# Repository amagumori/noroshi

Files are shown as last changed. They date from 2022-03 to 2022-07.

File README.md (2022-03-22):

# Noroshi
#### Portable LTE/Wifi Radio Terminal

Noroshi is a project that aims to explore the question:
**What capabilities enabled by the Internet are compelling, and...**
**How can we provide those capabilities in a way that is:**

+ More decentralized
+ More autonomous
+ More empowering for the individual?

The Internet of today is a vastly different place from the days of its infancy.  We've moved from a "many-servers" paradigm to a "many-clients" paradigm, as monolithic platforms have conquered the space.  The majority of Internet communication now exists in a TV-like paradigm, with a single-digit number of service providers.

These providers provide a variety of technological capabilities, each with unique social and cultural relevance, which overlap and can be broadly grouped into "live" and "static" groups, though the "liveness" is a spectrum.

### Live Capabilities
**Streaming** - Youtube, Twitch, IG Live, FB Live.
**Group Chat** - Discord, Slack, IRC (barely hanging on)
**Messaging** - Every platform

### Slow Capabilities
**Microblogging** - Twitter, IG, FB
**File Sharing** - Google Drive, Dropbox, OneDrive, etc
**Email** - Gmail, of course
**~~Blogging~~**  doesn't exist anymore
**~~Websites~~** don't exist anymore (in social or cultural relevance)

---

What would it look like to envision off-internet networking at a community or friend-group level?  And what capabilities could we provide while remaining free from the Internet or monolithic service providers?

The Internet provides a variety of capabilities, from realtime, streaming applications to static data.  We aim to attack this problem on both ends - one, the streaming, realtime, low-latency side of Internet functionality, using the NRF9160 to communicate over LTE; and the other, the slower, static side, using the ESP32 to enable peer-to-peer data exchange over Wifi.

### On the LTE side, a "radio" mode of using internet connectivity.  

+ Secure, frictionless, realtime push-to-talk communication, as with a VHF/UHF radio.

+ Broadcasting and receiving streaming audio, as with an FM radio.

Both of these applications are out of reach for the "regular citizen", especially within a city.  Ham radio does not enable encrypted communications, and is limited by regulation to a pure hobbyist pursuit.  Ham cannot be used for group-exclusive communications, and has a variety of limitations and frictions that prevent it from being a viable day-to-day communication tool.

On the other side, to set up a private VHF/UHF PTT capability within a city, a customer must lease radios from a vertically integrated provider, because only these will own repeater space on the local coverage points; you can get licensed, but a prohibitively expensive outlay is required to actually achieve full coverage in a metropolitan area.

These regulatory limitations prevent VHF/UHF from being used in an autonomous, secure, and self-sufficient manner.  Either you're a HAM, limited to communications-as-a-hobby - QSLs, etc; or you're a lessee of service from a provider.

This project aims to take a specific, compelling application of cell technology (low-latency audio streaming) and build a dedicated, stripped-down, and focused product for it, providing a more autonomous and open-source way to use IoT without relying on current monolithic tech ecosystems.

The goal of this project is to provide a different vision of communication over cell networks.  The value of this radio is in it being a dedicated object with a focused purpose and frictionless UX.  We aim for the main mode of interaction with the object to be physical, with the screen providing extremely concise information.  As far as possible from the interaction mode of a mobile app, we want this to be a physical device that fits well in the hand, has interactions recognizable by feel, and can be used without looking at the screen.

To illustrate this, mobile apps like Zello enable PTT functionality; but they also require buying into the entire cell phone ecosystem, from the hardware to the OS, and your communications go through an opaque signed binary to Zello's servers.  Cell phone apps have ever-present interaction friction at every level - multiple touch interactions to talk by default (unlocking the screen to hit the talk button, etc); coexisting with other apps on the phone, which can interfere with its operation or availability; difficulty of manipulating the phone in the hand; and so on.

Similarly, internet radio already exists; but there is no *dedicated* and simplified way to interact with it, and as such the technology is effectively dead.  Streaming video platforms such as Youtube or Twitch are now the dominant platform for audio streaming, because they provide lower barriers to entry and vastly better UX than Shoutcast or similar.  By providing a simple and frictionless way to broadcast and receive audio in realtime, we aim to empower individual users and rejuvenate a dying medium, with everyone being the owner, operator, and DJ of their own radio station, not through an app, but through a dedicated physical device.  Ultimately, I envision this as pushing a second age of radio, with individuals able to frictionlessly "speak" to an audience - every individual having space within the frequency spectrum, free of barriers to entry.

### Wifi / LoRa - Wifi for a peer-to-peer sneakernet, decoupled from the Internet.

The aim of the Wifi side of functionality is to provide a way to slowly and organically share static data among a local community without using the Internet - in other words, to provide a truly autonomous form of social networking.  

This aims at a similar area as existing platforms such as Mastodon that aim to provide decentralized alternatives to monolithic social networks. This project aims to provide a generic and open-ended framework for all types of information exchange - social applications like microblogging, as well as media and file sharing, forums, and wikis.  It also aims to provide a hardy and simple method for updating this shared state, that can be used not just with WiFi, but with other wireless connections - LoRa, etc.

## Design Methodology

We envision a community's "shared state" as a traditional filesystem, with each member possessing a directory.  At a global level, there are N numbers of dedicated *reserved filenames* that indicate the contextual meaning of the data.  a directory named "blog" will be viewed on the client side as that user's blog, similar to a twitter feed.  all files within that directory will be parsed as Markdown and displayed as blog entries in a time-sorted list based on the file's creation date.

### Connection

The public keys of "friends" in the community are indicated by the SSID broadcasted by the peer AP, and the shared secret is used as the WPA2 password.  With both devices in Station+SoftAP mode, operating in both modes simultaneously, we open a TCP socket connection.

### Syncing

After connecting to the peer, both clients send hashes of each "friend"'s directory, as well as timestamps of its last update.  both clients symmetrically use this info to determine the friends for which they own newer data, and the friends for which they own older data.

Another *reserved file* is the "friends" file.  This file exists within each person's directory at the top level, and describes permission groups (The ESP32 has a stripped-down libc, but runs on FreeRTOS, and has a very spare filesystem abstraction layer.)

We use **librsync**, specifically **rdiff**, to handle generating file signatures, deltas, and patching.  Signature files are generated AoT, not at connection time.

The friend directory trees are walked with **ftw**, permissions are checked, and the fds of new / updated signature files are pushed to a queue.  These signature files are compressed and sent; used to generate deltas; and deltas are compressed and sent, completing the sync process.

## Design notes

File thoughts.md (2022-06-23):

# ansible

---

chain of events on boot:

app_event_start

  concurrently:
    modem - on_all_states - setup()
    modem - EVENT_LTE_CONNECTED

    **ui** - load "codeplug"
    render start screen  

  EVENT_LTE_CONNECTED:
    **ui** show codeplug server list (contact list?)
    
    do ui stuff, handle inputs in ui until:

  EVENT_UI_CONNECT_TO_TALKSERVER:
    
    pass codeplug data to motorola in ui_msg 
    attempt mqtt connect
      success: MOTOROLA_EVENT_TALK_CONNECTED
      fail:    MOTOROLA_EVENT_TALK_CONNECT_FAIL
      
      motorola module handles everything from here, with events for when ppl talk etc.

  EVENT_UI_CONNECT_TO_STATION:
    
    pass codeplug data to radio in ui_msg
    attempt socket connect
      success: RADIO_EVENT_CONNECTED
      fail: RADIO_EVENT_CONNECT_FAIL
    
    etc.

  and that's pretty much it for now.
  other states of note:

    RADIO_EVENT_START_BROADCAST

---

[Scalable Protocols for Authenticated Group Key Exchange](https://www.cs.umd.edu/~jkatz/papers/multi-auth.pdf)

[Wideband Antenna - 8dBi](https://www.amazon.com/Wide-Band-Internal-LoRa-Antenna/dp/B08WJQ7ZS3)
700-2700Mhz but gotta see performance on the datasheet

[Battery Management IC shootout](https://hackaday.io/project/169422-iot-ups/log/177680-battery-management)

[1.3" 128x64 OLED module - $6.50](https://www.adafruit.com/product/5228)

### a low-power, secure push-to-talk device 

#### in the future, a portable silent sneakernet terminal, and a medium of secure data sync over other radio methods 

## TO DO

+ GPIO interface for buttons and leds.  reference sdk lib/dk_buttons

+ in-depth look at what's needed in the UI, how many inputs, how many views, and what they look like.  get concrete lists and trees for this.

+ suss out an explicit plan for doing voice over MQTT and what that protocol looks like.

+ begin testing radio module, delete all the cruft.

+ I2S interface to mic, speaker, and line out.  put this into the HW design in Kicad as well.

+ crypto - begin to look at what a secure talkgroup looks like and how to handle session establishment and TX / RX.

--

### wifi side - ESP8266

take a look at ESP datasheet.

my community versioned filesystem idea but certain items are ONLY synced in person, not over the internet.  

**1/27/22**

[I2S documentation for spekker](https://infocenter.nordicsemi.com/index.jsp?topic=%2Fstruct_nrf91%2Fstruct%2Fnrf9160.html&cp=2_0)

probably handle mic and speaker with both sides of the I2S interface for better quality than PDM

the I2S driver already implements dubble bubfering behind the scenes, so that's one less thing to do, this way we can shove audio frames coming off the MQTT interface directly towards the I2S RX / TX buffers and then just play what we get, configuring the RXTXDCNT.MAXWORDS as needed.

**1/22/22**

completely dropping the whole LWm2m thing

MQTT with QOS-1 (ack'd) frames.
assemble in order on the recipient end.
send a header with frame count.

### RTOS modules (zephyr)

UI module - UI events, interactions through LVGL

HW module - the physical buttons - this is tightly coupled to UI and could even combine ...?

MODEM module - self explanatory

do you separate out MQTT protocol layer into its own module? leaning towards ...no...

*radio protocol over LTE*

i wanted to just do LWm2m and i'll fall back if my idea ends up not working, but...

we essentially just want in-order packet delivery.

so, you make a recording using the PDM microphone, let's say 30 seconds max transmit time.

this gets split into frames, with a header:

**header**

+ u32 id of transmitter

+ u16 frame count

+ u32[] recipient ids, and if this[0] is 0 then it's a public message.  server handles that

**frame**

+ u16 sequence number

+ u16 buffer of FRAMESIZE 

but actually i don't like this.  i think..

header: transmitter id, recipients

frame: sequence number, buffer, bool done?

this way we can opportunistically shove encoded frames out the door
instead of filling a on-device buffer first.

*LTE-M / NB-IoT*

NRF9160

enables PTT, in concert with a MQTT server.

kicking around the idea of having "freqs" on the server.

enable both internet-radio (RX only) and communication (TX / RX) applications.

*Wi-Fi*

ESP8266 etc.

enables "distributed sneakernet".

essentially to have a...something, git repo + wiki + forum + fileserver, some kind of distributed locus of info (files), "slow" communications (long-form discussions, "letters") , and ... other stuff

the ESP8266 passively updates this network, when in range of a known and trusted *beacon*.

`security weak point!` 
*beacon* key exchange can be done over LTE / Internet or via NFC, in person.

the group data store can be viewed as some kind of tree that can be diff'd, similar to git or react?

*LoRaWAN* 

only having Wifi capability severely limits the capabilities of *beacons*.

LoRa enables better capability for long-range, passive syncing of the datastore state.

the more "mirrors" / *beacons* the better, so it follows that having more of them be able to connect is important.

--- 

there's a fundamental question of whether to enable backchanneling over the internet at all.

at the very least, file/comm permissions should allow a "No-Internet" status.
these updates would still be synced to the state (not their actual content, but a dummy update).

the "No-Internet" status would mark them for updating if ansible receives a diff from the local network with the relevant data.

if updated via internet, would only display a "Encrypted: Local Only" message as displayed in the rendering of the wiki/filestore/whatever.

---

the radio stores contact sets, from entire-community-level to smaller subgroups.

files are worked on a sans-internet computer, then updates are encrypted and synced to radio.

radio then transfers updates to each user, who holds a copy of the total state.
this happens over LTE

## Hardware Design

**AS SIMPLE AS POSSIBLE**
that means as few inputs as possible.

all physical buttons, no touch.  medium-rugged and repairable design.

shooting for ~1.75" width x 4-5"?  depth whatever.  it can be a lil thicc

3Ah+ battery.  aiming for slightly chunky nextel form factor...but appealing.

pcbway - UTR-8100 resin, dyed after the fact?

OLED module fr sure.  1-1,5"

*input interface*

+ PTT button, located as on a motorola XPR

PTT button is essentially a no go because it's for PTT and only PTT, always.

+ up/down buttons on PTT side.

+ thumb button on opposite side.

this way you grip across face of radio, index finger PTT, thumbs up/down 

+ some kind of wheel.  probably volume / power knob located top.

this is also off limits design wise.  volume / pwr only.

it's gonna need 1 or 2 more inputs than this but hopefully not many more.

*connectors*

SMA(m) connector.

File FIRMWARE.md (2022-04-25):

# hardware

## audio stage

MAX9880 audio codec - I2S - both voiceband and high-quality stereo input / dac / amp covered
audio out also covered 

# firmware structure

microphone interface: 

https://infocenter.nordicsemi.com/index.jsp?topic=%2Fcom.nordic.infocenter.nrf52832.ps.v1.1%2Fpdm.html

## transmit

MQTT session is set up on NRF9160 over TLS.

Microphone -> TLV320ADC or similar -> NRF9160 I2S input.

TLV320 can filter up the signal real nice to give to Codec2.

NRF9160's FPU: Codec2/FreeDV encode payload from voice data.
 
this payload could be a stack of smaller payloads, or just one big payload.

at this point, encrypt with CryptoCell or whatever?  but don't, at first..

voice payload is TX'd to MQTT broker.

## receive

decrypt

Codec2 / FreeDV decode

i2s/c out -> amp -> speaker

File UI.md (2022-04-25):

# UI Plan

#### boot screen

# select server

PTT and "radio" happen over a "repeater" server.
you have a list of these in the "codeplug". 

codeplug will automatically GET each server with your shared secret, if you have it.

  if auth:
    server will return list of your auth'd talkgroups and active stations

  if no auth:
    servers will return list of public stations

if auth fails / no key, list item for server will show NO-AUTH
if auth success, list item for server will look good

we want a way to dynamically access anyone's "radio station" at any time
without a server-switch interaction

we want to send a MQTT notify if a talkgroup member starts broadcasting

and then if we want to connect to that "radio station"...
  we open a different (or OTHER) socket conn to that server.

broadcasting happens thru your "home" repeater by default

## PTT

### select talkgroup

#### connecting to server... view

opens MQTT connection to server, start listening

#### PTT view: talkgroups and members

default view shows active talkgroups

alternate view lists all server members

#### Talkgroup view

talkgroup name, then "talking" view, if someone's talking

alternate view lists all talkgroup members

#### talking (transmitting) view

"transmitting" icon + name of talkgroup + waveform view

#### listening ( receiving ) view

talker's user icon + talkers name + waveform view

---

#### connecting to radio... view

have a "tuning" sound effect like JSRF

## Radio

### tuning view

show list of all active stations on all servers 

  public stations on un'authd servers
  
  public + private stations on auth'd servers

Broadcaster's user icon OR custom station icon

station name

broadcaster name: repeater name

lil waveform animation view??

### Radio Station ID Jingle

an audio clip "header" that plays when you connect.

broadcaster sends this to repeater when beginning broadcast

repeater saves it for the life of the broadcast session, sends it to each new listener

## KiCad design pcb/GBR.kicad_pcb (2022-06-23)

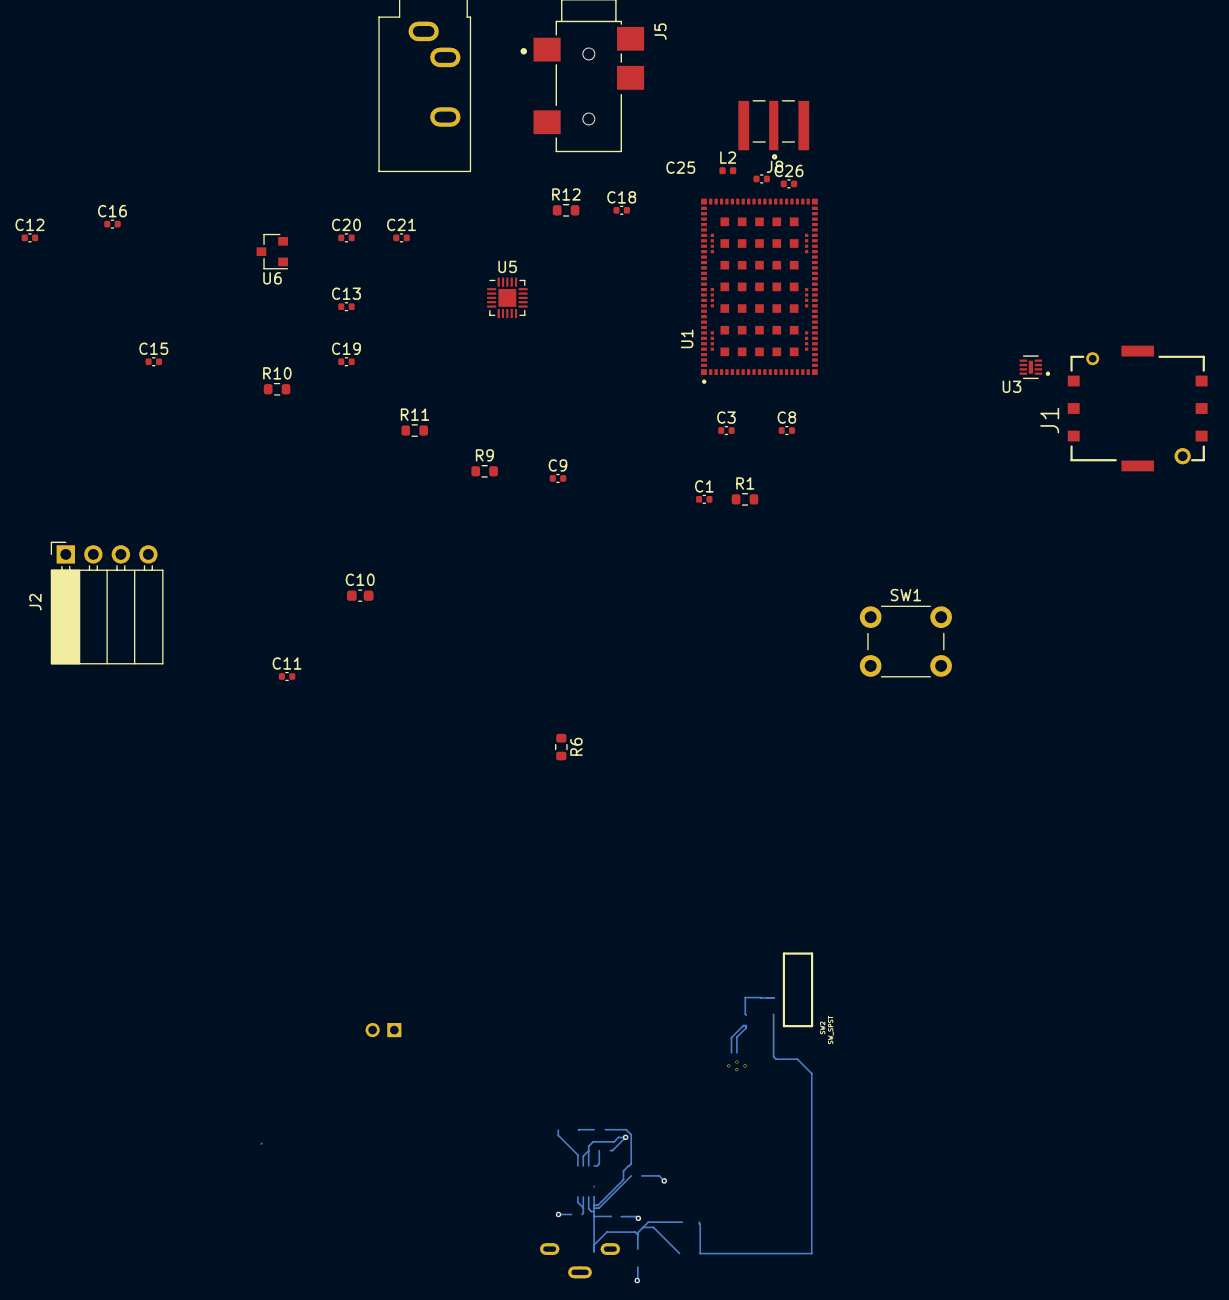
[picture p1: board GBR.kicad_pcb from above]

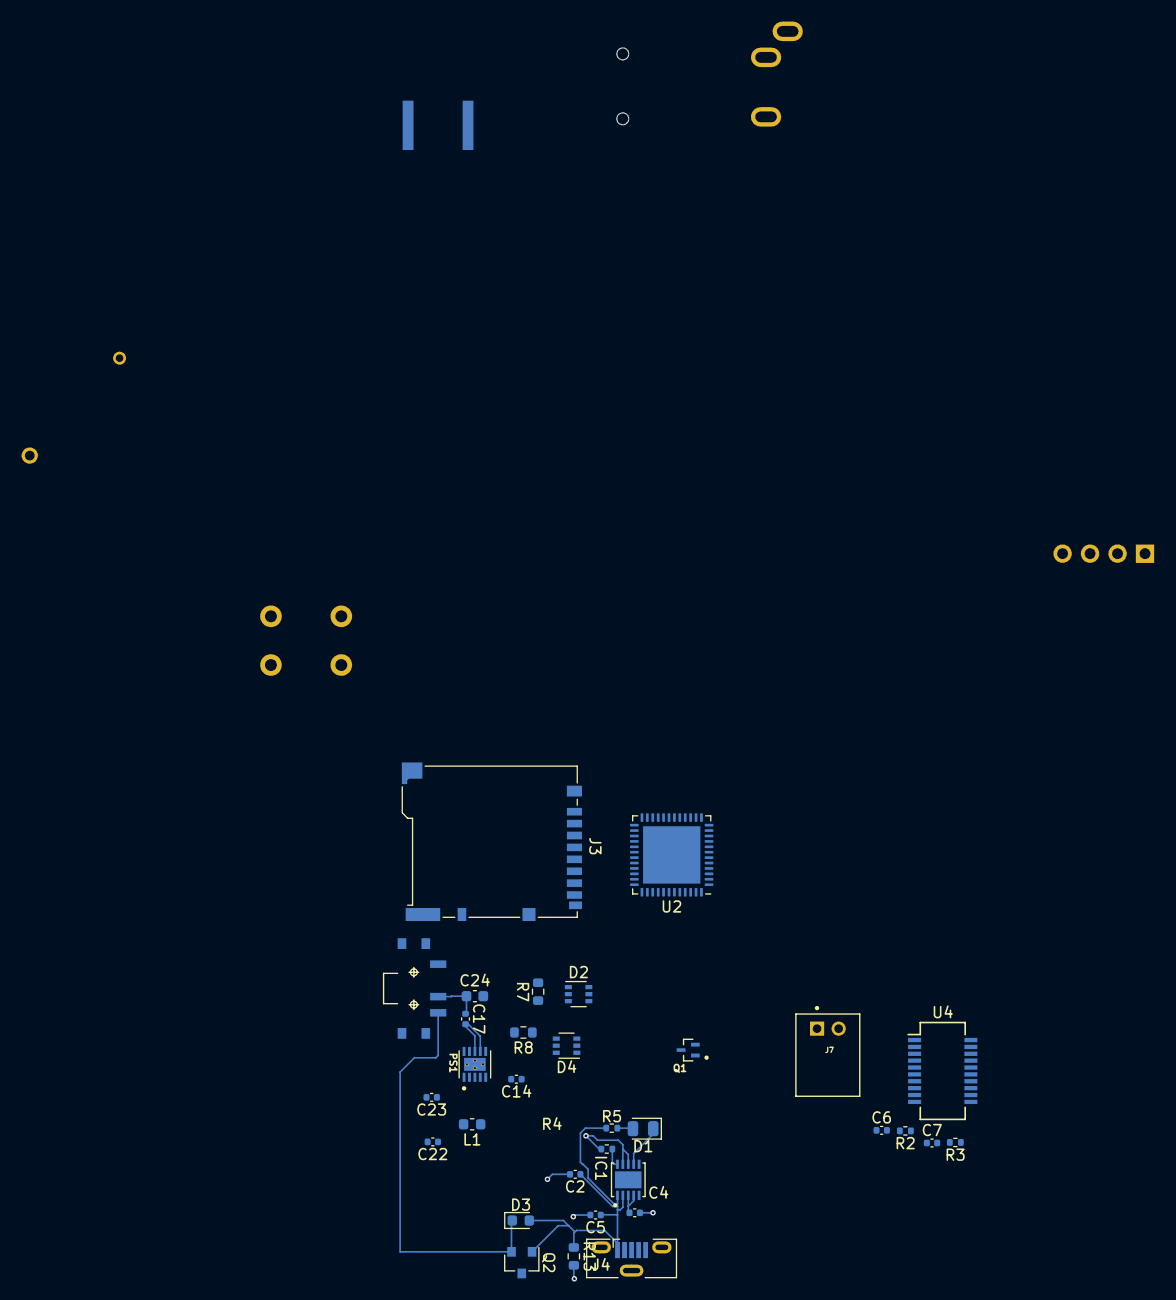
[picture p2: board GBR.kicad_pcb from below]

Board: 4 copper layers, 65 parts (32 on the bottom side), 59 nets.

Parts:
C1: 4.7uF; C_0402_1005Metric
C2: 1u; C_0402_1005Metric
C3, C8: 4.7u; C_0402_1005Metric
C4: C; C_0402_1005Metric
C5, C11, C13, C15, C18, C19: 0.1uF; C_0402_1005Metric
C6, C7: 47pF; C_0402_1005Metric
C9: 47u; C_0402_1005Metric
C10: C; C_0603_1608Metric
C12, C16, C20, C21: 1uF; C_0402_1005Metric
C14: 0.1u; C_0402_1005Metric
C17, C22, C23: 10u; C_0402_1005Metric
C24: 10uF; C_0603_1608Metric
C25, C26: 50V 15pF; C_0402_1005Metric
D1: LED; LED_0805_2012Metric
D2, D4: BAV70S; SOT-363_SC-70-6
D3: D_Schottky; D_0603_1608Metric
IC1: MCP73113-16SI_MF; SON50P300X300X100-11N(1)
J1: SIM8051-6-0-14-01-X-REVD; GCT_SIM8051-6-0-14-01-X-REVD
J2: ADAFRUIT OLED CONN; PinSocket_1x04_P2.54mm_Horizontal
J3: Micro_SD_Card; microSD_HC_Hirose_DM3BT-DSF-PEJS
J4: USB_B_Micro; USB_Micro-B_Molex-105133-0001
J5: headphones; CUI_SJ2-35863A1-SMT-TR
J6: line in; Jack_3.5mm_CUI_SJ1-3533NG_Horizontal
J7: Conn_01x02_Male; JST_S2B-PH-K-S(LF)(SN)
J8: LTE_ANT_SMA; TAOGLAS_EMPCB.SMAFSTJ.B.HT
L1: 1.5uH; L_0603_1608Metric
L2: 250mA 39nH; L_0402_1005Metric
PS1: TPS63031DSKR; SON50P250X250X80-11N
Q1: RE1C002UNTCL; SOTFL50P160X85-3N
Q2: DMG2301L; SOT-23
R1: 10K; R_0603_1608Metric
R2, R3: 27; R_0402_1005Metric
R4: R_PROG; R_0402_1005Metric
R5: R_US; R_0402_1005Metric
R6, R7, R9: 1M; R_0603_1608Metric
R8: 100k; R_0603_1608Metric
R10, R11: 4.7K; R_0603_1608Metric
R12: 2.2K; R_0603_1608Metric
R13: 100K; R_0603_1608Metric
SW1: SW_Push; SW_PUSH_6mm
SW2: SW_SPST; KPS-1290
U1: NRF9160-SICA-R7; XCVR_NRF9160-SICA-R7
U2: ESP32-PICO-D4; QFN-48-1EP_7x7mm_P0.5mm_EP5.3x5.3mm
U3: TPD3F303DQDR; SON40P170X135X80-9N
U4: FT231XS; SSOP-20_3.9x8.7mm_P0.635mm
U5: SGTL5000XNLA3; QFN-20-1EP_3x3mm_P0.4mm_EP1.65x1.65mm
U6: MCP1700-1202E_SOT23; SOT-23

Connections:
+1V8: C13.1, C16.1, U5.20, U6.2
+3V3: C3.1, C8.1, C11.1, C12.1, C15.1, C22.1, C23.1, PS1.1, PS1.10, R1.1, R9.1, R10.1, R11.1, U1.12, U1.22, U1.102, U2.1, U2.43, U2.46, U5.3, U5.12, U6.3
+BATT: C4.1, IC1.3, IC1.4, J7.2, Q2.3
-BATT: C1.2, C2.2, C3.2, C4.2, C5.2, C6.2, C7.2, C8.2, C9.2, C10.1, C11.2, C12.2, C13.2, C14.2, C15.2, C16.2, C19.2, C22.2, C23.2, C24.2, C25.2, IC1.8, IC1.9, J1.C5, J4.5, J4.6, J7.1, L2.2, PS1.3, PS1.9, PS1.11, Q1.2, R4.1, R6.1, R7.2, R13.2, U1.1, U1.5, U1.9, U1.14, U1.17, U1.21, U1.27, U1.31, U1.36, U1.41, U1.44, U1.47, U1.50, U1.52, U1.56, U1.60, U1.62, U1.63, U1.65, U1.66, U1.72, U1.74, U1.75, U1.76, U1.77, U1.78, U1.79, U1.80, U1.81, U1.82, U1.85, U1.90, U1.94, U1.98, U1.103_1, U1.103_2, U1.103_3, U1.103_4, U1.103_5, U1.103_6, U1.103_7, U1.103_8, U1.103_9, U1.103_10, U1.103_11, U1.103_12, U1.103_13, U1.103_14, U1.103_15, U1.103_16, U1.103_17, U1.103_18, U1.103_19, U1.103_20, U1.103_21, U1.103_22, U1.103_23, U1.103_24, U1.103_25, U1.103_26, U1.103_27, U1.103_28, U1.103_29, U1.103_30, U1.103_31, U1.103_32, U1.103_33, U1.103_34, U1.103_35, U2.49, U3.9, U4.3, U4.15, U5.21
/EN: Q1.1, R6.2
/SIM_CLK: U1.46, U3.7
/SIM_IO: U1.48, U3.6
/SIM_RST: U1.43, U3.8
/VIN: C17.1, C24.1
ESP_RESET: C1.1, R1.2, U2.9
LRCLK: U1.87, U5.14
LTE_ANT: C25.1, C26.2, U1.61
MCLK: U1.86, U5.13
MIC: C18.1, R12.1
MODE\2.2F: D2.4, D4.4
unnamed: C6.1, J4.2, R2.2
unnamed: C7.1, J4.3, R3.2
unnamed: C9.1, U1.13
unnamed: C10.2, U4.16
unnamed: C14.1, C17.2, PS1.5, PS1.7, PS1.8
unnamed: C18.2, U5.10
unnamed: C19.1, U5.5
unnamed: C20.2, U5.8
unnamed: C21.1, J6.T
unnamed: C21.2, U5.9
unnamed: C26.1, J8.1, L2.1
unnamed: D1.1, IC1.7
unnamed: D1.2, R5.1
unnamed: D2.3, R7.1, R8.2
unnamed: D3.1, Q2.2
unnamed: IC1.10, R4.2
unnamed: J1.C2, U3.1
unnamed: J1.C3, U3.2
unnamed: J1.C7, U3.3
unnamed: J3.2, U2.11
unnamed: J3.3, U2.30
unnamed: J3.4, U2.26
unnamed: J3.5, U2.31
unnamed: J3.7, U2.32
unnamed: J3.8, U2.33
unnamed: L1.1, PS1.4
unnamed: L1.2, PS1.2
unnamed: PS1.6, Q1.3, R8.1
unnamed: R9.2, U1.101
unnamed: R10.2, U5.19
unnamed: R11.2, U5.18
unnamed: R12.2, U5.11
unnamed: U1.6, U1.7, U1.8, U1.10, U1.11, U1.51, U1.68, U1.69, U1.70, U1.71, U1.73, U1.104, U1.105, U1.106, U1.107, U1.108, U1.109, U1.110, U1.111, U1.112, U1.113, U1.114, U1.115, U1.116, U1.117, U1.118, U1.119, U1.120, U1.121, U1.122, U1.123, U1.124, U1.125, U1.126, U1.127
unnamed: U2.3, U2.4
OLED_MISO: J2.3, U1.96
OLED_MOSI: J2.2, U1.97
OLED_SCK: J2.4, U1.95
P0.31\NRF_PS_EN\1.1B: D2.1, U1.89
RTC_PS_EN\3.6C: D2.5, D4.5
SCLK: U1.30, U5.15
SDIN: U1.84, U5.17
SDOUT: U1.83, U5.16
SIM_VCC: J1.C1, U1.49, U3.5
VBUS: C2.1, C5.1, D2.2, D3.2, IC1.1, IC1.2, J4.1, Q2.1, R5.2, R13.1, U4.6

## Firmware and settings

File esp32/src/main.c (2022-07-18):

#include "wifi.h"
#include "friends.h"

#define DUMMY_FRIENDS_MAX 64 

struct ht_table *mac_ip_table;

enum {
  WIFI_EVENT_DISCONNECTED = 1 << 0,
  WIFI_EVENT_CONNECTED = 1 << 1,
};

typedef struct friend_t {
  u32 id;
  u8 ssid[32];  // ssid / id
  u8 pass[64];
} friend;

typedef struct friend_sta_t {
  u8 mac[6];
  esp_ip4_addr_t ip;
} friend_sta;

friend_t friends_list[DUMMY_FRIENDS_MAX];

uint8_t friends_list[NUM_FRIEND_IDS][33]
wifi_ap_record_t access_points[20];
TaskHandle_t wifi_task_handle;
TimerHandle_t reconnect_timer;
EventGroupHandle_t wifi_event_group;

typedef enum {
  ESP_STATE_BOOT,
  ESP_STATE_IDLE,
  ESP_STATE_SCAN,
  ESP_STATE_CONNECTING,
  ESP_STATE_CONNECT_FAIL,
  ESP_STATE_CONNECT_SUCCESS,
  ESP_STATE_PEER_SYNCING,
  ESP_STATE_PEER_SYNC_SUCCESS,
  ESP_STATE_PEER_SYNC_FAIL,
  ESP_STATE_WIPING_DATA,
  ESP_STATE_WIPED,
  ESP_STATE_HOME_SYNCING,
  ESP_STATE_HOME_SYNC_FAIL,
  ESP_STATE_HOME_SYNC_SUCCESS
  ESP_STATE_SHUTDOWN
} AppState;

const QueueHandle_t peer_ip_queue;
const static EventGroupHandle_t wifi_event_group;
uint32_t irq_source;
TaskHandle_t irqHandlerTask = NULL;

void irqHandler( void *pvParams ) {
  _ASSERT( (uint32_t)pvParams == 1 );
  uint32_t irq_source;

  for ( ;; ) {
    xTaskNotifyWait(0x00,           // don't clear bits on entry
                    ULONG_MAX,      // clear all bits on exit
                    &irq_source,    // receives notif value
                    portMAX_DELAY); // wait forever
    if ( irq_source & UNMASK_IRQ ) {
      irq_source &= ~MASK_IRQ;
    } else if ( (irq_source & MASK_IRQ) ) {
      // LoRa check happens here - os_querytimecriticaltasks
      continue;
    }

    if ( irq_source & DISPLAY_IRQ ) {
      display_refresh();
    }
    // sleep cycle happens in ISR too.
    // we can handle sending state over UART in a lowest-prio task
  }
}

void IRAM_ATTR doIrq( int irq ) {
  BaseType_t xHigherPriorityTaskWoken = pdFALSE;
  xTaskNotifyFromISR(irqHandlerTask, irq, eSetBits, &xHigherPriorityTaskWoken);
  if ( xHigherPriorityTaskWoken ) {
    portYIELD_FROM_ISR();
  }
}

////


static void init_nvs( void ) {
  esp_err_t err = nvs_flash_init();
  if ( err == ESP_ERR_NVS_NO_FREE_PAGES || err == ESP_ERR_NVS_NEW_VERSION_FOUND ) {
    ESP_ERROR_CHECK(nvs_flash_erase());
    err = nvs_flash_init();
  }
  ESP_ERROR_CHECK(err);
}

/*
 * since our app flow is relatively simple, should use an enum + direct-to-task notifs.
 * we make an enum full of u32 integer flags.
 * use xTaskNotify if the task only needs to know one piece of state at a time
 * or xTaskNotifyIndexed if it has to be aware of multiple different state flags.
 *
 * this is way faster and more performant / lower-RAM than using event groups or messaging etc.
 *
 * i think one top-level "broker" task controlling state mgmt 
 * but the lower-level sync type tasks have ultimate priority and give back to broker only
 * when they're ready to relinquish.
 *
 */

void app_main( void ) {


/* HARDWARE SETUP */


  // SD CARD / FILESYSTEM
  sdmmc_host_t host = SDMMC_HOST_DEFAULT();
  sdmmc_slot_config_t slot_config = SDMMC_SLOT_CONFIG_DEFAULT();

  // SDMMC PINS
  gpio_set_pull_mode(15, GPIO_PULLUP_ONLY); // CMD
  gpio_set_pull_mode(2, GPIO_PULLUP_ONLY);  // D0
  gpio_set_pull_mode(4, GPIO_PULLUP_ONLY);  // D1
  gpio_set_pull_mode(12, GPIO_PULLUP_ONLY); // D2
  gpio_set_pull_mode(13, GPIO_PULLUP_ONLY); // D3 

  esp_err_t err = init_sd();
  if ( err != ESP_OK ) {
    ESP_LOGE(TAG, "Failed to initialize SD in main.");
  }

  // WIFI
  wifi_event_group = xEventGroupCreate();
  ESP_ERROR_CHECK( esp_event_loop_create_default() );
  init_wifi( wifi_event_group );


  // create the tasks

//  if ( xTaskCreate( 
}

static void wifi_event_handler( void *arg, esp_event_base_t event_base, i32 event_id, void *event_data ) {

  if ( event_id == WIFI_EVENT_AP_STACONNECTED ) {
    wifi_event_ap_staconnected_t *event = (wifi_event_ap_staconnected_t *) event_data;
    // now this is dumb.
    ht_insert( mac_ip_table, (char*)event.mac, (char*)0 );
    ESP_LOGI(TAG, "station "MACSTR" join, AID=%d", MAC2STR(event->mac), event->aid);
  }

  /*
 *
 * thought i was going to have to use a hashtable to associate stations with ips etc.
 * turns out there actually is an undocumented API function to get the station list with assigned IPs. */

  if ( event_id = IP_EVENT_AP_STAIPASSIGNED ) {
    esp_ip4_addr_t station_ip = ( ip_event_ap_staipassigned_t) event_data->ip;
    printf("station assigned ip: %s\n", ip4addr_ntoa(&station_ip) ); 
    // rather than trying to associate mac and ip, we just connect once we receive an ip assign.
    // 0 = immediately return if queue ful.
    xQueueSendToFront( peer_ip_queue, station_ip, 0 );
  }
  

  if ( event_id == WIFI_EVENT_AP_STADISCONNECTED ) {
    wifi_event_ap_stadisconnected_t *event = ( wifi_event_ap_stadisconnected_t*) event_data;
    ESP_LOGI(TAG, "station "MACSTR" leave, AID=%d", MAC2STR(event->mac), event->aid);
  }

}
// register event handler with base types of both wifi and ip 


int reconnect_callback( TimerHandle_t timer ) {

  ESP_ERROR_CHECK( esp_wifi_scan_start( &scan_config, false ) );
  ESP_ERROR_CHECK( esp_wifi_scan_get_ap_records( 20, access_points ) );
   
  for ( int i=0; i < NUM_FRIEND_IDS; i++ ) {
    for ( int j=0; j < 20; j++ ) {
      long ssid = strtol( access_points[j].ssid )

      if ( strncmp( friends_list[i].ssid, ssid, 32 ) == 0 ) {

        
        

        strncpy( ap_config.ssid, access_points[j].ssid, 33 );
        ap_config.ssid_len = strnlen( ap_config.ssid, 32 );
        strncpy( ap_config.password, friends_list[i].pass, 64 );
        ap_config.authmode = WIFI_AUTH_WPA3_PSK;
        ap_config.pairwise_cipher = WIFI_CIPHER_TYPE_AES_GMAC256;

        

      } else {

        ESP_LOGI(tag, "failed to find a valid password for id %s:", access_points[j].ssid );
        return 0;

      }

      esp_err_t connect_err;
      connect_err = esp_wifi_connect();

      if ( connect_err != ESP_OK ) {

        ESP_LOGE(tag, "failed to connect to ssid %s", ap_config.ssid );
        return 0;

      } else {
        // associate friend-id with IP 

        xEventGroupSetBits( wifi_event_group, WIFI_EVENT_CONNECTED );
        return 1;
      }
    }
  }

}


// https://techtutorialsx.com/2019/09/22/esp32-arduino-soft-ap-obtaining-ip-address-of-connected-stations/

void task_wifi ( void *pvParam ) { 
  while ( ;; ) {
    switch( xEventGroupGetBits( wifi_event_group ) ) {
      case WIFI_EVENT_DISCONNECTED:
        // just return because we handle this in the timer
        return;
      // need separate flags for connected to AP and someone connected to US
      case WIFI_EVENT_CONNECTED:

        // components/esp_netif/include/esp_netif_sta_list.h
        // this is undocumented.  LOL cool.
        wifi_sta_list_t wifi_sta_list;
        esp_netif_sta_list_t *netif_sta_list;

        memset(&wifi_sta_list, 0, sizeof(wifi_sta_list_t));
        memset(&netif_sta_list, 0, sizeof(esp_netif_sta_list_t));

        esp_wifi_ap_get_sta_list(&wifi_sta_list);
        esp_netif_get_sta_list(&wifi_sta_list, &tcpip_sta_list);
        
        for ( int i=0; i < netif_sta_list.num; i++ ) {

          esp_netif_sta_info_t station = netif_sta_list[i];
          // item is queued by copy
          xQueueSend( peer_ip_queue, &station, 0 );

        } 
    }
    if ( xEventGroupGetBits( wifi_event_group ) == WIFI_EVENT_NO_SSIDS_FOUND ) {

    }
  }
}

void wifi_init ( void ) {
  wifi_init_config_t config = WIFI_INIT_CONFIG_DEFAULT();

  mac_ip_table = new_ht();

  ESP_ERROR_CHECK( esp_wifi_init(&config) );
ESP_ERROR_CHECK( esp_event_handler_instance_register( WIFI_EVENT, ESP_EVENT_ANY_ID, &wifi_event_handler,
                                                        NULL, NULL ) );
  wifi_config_t ap_config = {
    .ap = {
      .ssid = 
      .ssid_len =
      .channel = 
      .password = 
      .max_connection =
      .authmode = 
      .pmf_cfg = {
        .required = false,  // should set to true for production
      },
    },
  };

  // @FIXME
  wifi_config_t sta_config = {
    .sta = {
      .ssid = 
      .password = 
      .scan_method = WIFI_ALL_CHANNEL_SCAN,
      .sort_method = WIFI_CONNECT_AP_BY_SIGNAL,   // or WIFI_CONNECT_AP_BY_SECURITY
      .threshold = {
        .rssi = 60,   // min acceptable RSSI
        .authmode = WIFI_AUTH_WPA2_PSK  // acceptable auth mode
      },
      .pmf_cfg = {
        .required = false,  // set to true for production
      },
    },
  };

  // https://docs.espressif.com/projects/esp-idf/en/latest/esp32/api-guides/wifi.html

  wifi_scan_config_t scan_config = { 0 };
  // for now we're listening for beacon frames, but this is a massive concern.
  // is it safer to active scan and have listeners silent?  probably.
  scan_config.scan_type = WIFI_SCAN_TYPE_PASSIVE;

  ESP_ERROR_CHECK( esp_wifi_set_mode( WIFI_MODE_APSTA )
  ESP_ERROR_CHECK( esp_wifi_set_config( WIFI_IF_AP, &ap_config ) );
  ESP_ERROR_CHECK( esp_wifi_set_config( WIFI_IF_STA, &sta_config ) );

  // task, name, stack depth in words, params passed in, priority 0-25
  xTaskCreate( &task_wifi, "Wifi", 10000, wifiParam, 23 );
  reconnect_timer = xTimerCreate( "reconnectTimer", 
                                  pdMS_TO_TICKS(15000),
                                  pdTRUE,
                                  0,
                                  reconnect_callback );
  // create list of ips to connect and sync.
  peer_ip_queue = xQueueCreate( 10, sizeof(esp_ip4_addr_t) );

  wifi_event_group = xEventGroupCreate();
  // check wifi_event_group not null

  // false - non-blocking / async
  ESP_ERROR_CHECK( esp_wifi_scan_start( &scan_config, false ) );

}

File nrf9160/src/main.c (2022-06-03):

#include <device.h>
#include <drivers/display.h>
#include <stdio.h>
#include <string.h>

#include <zephyr.h>
#include <lvgl.h>

#include "modules/ui.h"

#define LOG_LEVEL CONFIG_LOG_DEFAULT_LEVEL
#include <logging/log.h>
LOG_MODULE_REGISTER(app);

// include logo image as C bitmap array
extern const lv_img_dsc_t logo;

struct app_msg {
	union {
		struct modem_event modem;
		struct ui_event ui;
		struct radio_event radio;
		struct motorola_event motorola;
		struct server_event server;
		struct app_event app;
	} module;
};

#define APP_QUEUE_ENTRY_COUNT		10
#define APP_QUEUE_BYTE_ALIGNMENT	4

K_MSGQ_DEFINE( msgq_app, sizeof( struct app_msg ), APP_QUEUE_ENTRY_COUNT, APP_QUEUE_BYTE_ALIGNMENT );

static struct module_data self = {
	.name = "app",
	.msg_q = &msgq_app,
	.supports_shutdown = true,
};

/* Convenience functions used in internal state handling. */
static char *state2str(enum state_type new_state)
{
	switch (new_state) {
	case STATE_INIT:
		return "STATE_INIT";
	case STATE_RUNNING:
		return "STATE_RUNNING";
	case STATE_SHUTDOWN:
		return "STATE_SHUTDOWN";
	default:
		return "Unknown";
	}
}

/* enumerate substates a bit later
 *
static char *sub_state2str(enum sub_state_type new_state)
{
	switch (new_state) {
	case SUB_STATE_ACTIVE_MODE:
		return "SUB_STATE_ACTIVE_MODE";
	case SUB_STATE_PASSIVE_MODE:
		return "SUB_STATE_PASSIVE_MODE";
	default:
		return "Unknown";
	}
}
*/

static void state_set(enum state_type new_state)
{
	if (new_state == state) {
		LOG_DBG("State: %s", state2str(state));
		return;
	}

	LOG_DBG("State transition %s --> %s",
		state2str(state),
		state2str(new_state));

	state = new_state;
}

static void sub_state_set(enum sub_state_type new_state)
{
	if (new_state == sub_state) {
		LOG_DBG("Sub state: %s", sub_state2str(sub_state));
		return;
	}

	LOG_DBG("Sub state transition %s --> %s",
		sub_state2str(sub_state),
		sub_state2str(new_state));

	sub_state = new_state;
}


static bool event_handler(const struct event_header *eh)
{
	struct app_msg_data msg = {0};
	bool enqueue_msg = false;

	if (is_cloud_module_event(eh)) {
		struct cloud_module_event *evt = cast_cloud_module_event(eh);

		msg.module.cloud = *evt;
		enqueue_msg = true;
	}

	if (is_app_module_event(eh)) {
		struct app_module_event *evt = cast_app_module_event(eh);

		msg.module.app = *evt;
		enqueue_msg = true;
	}

	if (is_data_module_event(eh)) {
		struct data_module_event *evt = cast_data_module_event(eh);

		msg.module.data = *evt;
		enqueue_msg = true;
	}

	if (is_sensor_module_event(eh)) {
		struct sensor_module_event *evt = cast_sensor_module_event(eh);

		msg.module.sensor = *evt;
		enqueue_msg = true;
	}

	if (is_util_module_event(eh)) {
		struct util_module_event *evt = cast_util_module_event(eh);

		msg.module.util = *evt;
		enqueue_msg = true;
	}

	if (is_modem_module_event(eh)) {
		struct modem_module_event *evt = cast_modem_module_event(eh);

		msg.module.modem = *evt;
		enqueue_msg = true;
	}

	if (is_ui_module_event(eh)) {
		struct ui_module_event *evt = cast_ui_module_event(eh);

		msg.module.ui = *evt;
		enqueue_msg = true;
	}

	if (enqueue_msg) {
		int err = module_enqueue_msg(&self, &msg);

		if (err) {
			LOG_ERR("Message could not be enqueued");
			SEND_ERROR(app, APP_EVT_ERROR, err);
		}
	}

	return false;
}

static void on_all_states( struct app_msg *msg ) {
  //if ( IS_EVENT( msg, 
}


void main ( void ) {

  int err;
  struct app_msg msg;

  if ( event_manager_init() ) {
    LOG_ERR( "APP: couldn't initialize event manager, rebooting.");
    k_sleep( K_SECONDS(4) );
    sys_reboot(SYS_REBOOT_COLD);
  } else {
    module_set_state( MODULE_STATE_READY );
    SEND_EVENT( app, APP_EVENT_START );
  }

  self.thread_id = k_current_get();
  err = module_start(&self);
  if ( err ) {
    LOG_ERR("failed starting module: error %d.", err );
    SEND_ERROR( app, APP_EVENT_ERROR, err );
  }

  // watchdog?

  while ( true ) {
    module_get_next_msg(&self, &msg);

    switch ( state ) {

    }
  }
}




}

EVENT_LISTENER( MODULE, event_handler );
EVENT_SUBSCRIBE( MODULE, modem_event );
EVENT_SUBSCRIBE( MODULE, motorola_event );  // i badly need a better naming convention.
EVENT_SUBSCRIBE( MODULE, radio_event );
// probably implement event messages from hw too later?
EVENT_SUBSCRIBE( MODULE, server_event );
EVENT_SUBSCRIBE( MODULE, input_event );

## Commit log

2022-01-09 pdm mic device interface
2022-02-02 began implementing UART interface.
2022-02-06 adding module threads and other stuff.
2022-02-24 adding ESP32 firmware
2022-03-21 working at rdiff syncing on ESP32 side, implemented UART interface for sending ESP32 state to NRF9160.
2022-04-08 ESP32: rsync, exchanging file info over socket before generating signatures.
2022-06-23 adding kicad project and PCB stuff.
    [GBR.kicad_pcb, GBR.sch]
2022-07-16 esp32 stuff
2022-07-17 beginning to tie the ESP32 side together.
